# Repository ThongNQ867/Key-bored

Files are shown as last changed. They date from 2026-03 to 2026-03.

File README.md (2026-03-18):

# Key-bored
This is a split keyboard that uses XIAO nRF52840 and MX switches with hotswap, LED and 3-D printed case.

This project is a Split wireless keyboard that run on 2 Xiao nRF52840 on each side. This keyboard runs on ZMM firmware and used MX switches. I made this project because split keyboards are very expensive and I think making one will help people have the similar experience with relatively lower price. Also, the parts like Xiao are reuseable for many projects, making it really cost effective. 

How to use:
- After print the PCBA from JLC PCB or order the parts and hand soldered them, solder the hotswap sockets, Xiao, JST pins into the pcb, and finally attach the swithces into the socket.
- Wire the Xiao with your computer and flash each of them with the firmware
Basicaly we got a working keyboard now.
- For the case, put the heat inserts in, lay the pcb on top and screw it with M3 (3mm) screws.

The assembled design should look like this

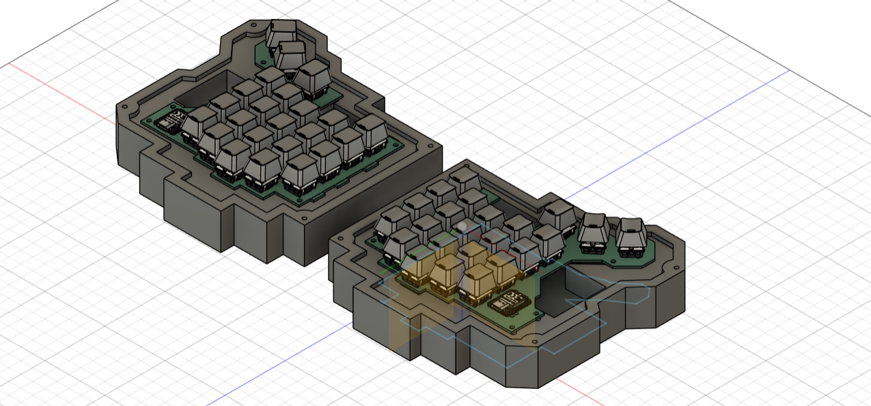
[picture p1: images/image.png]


The PCB design:

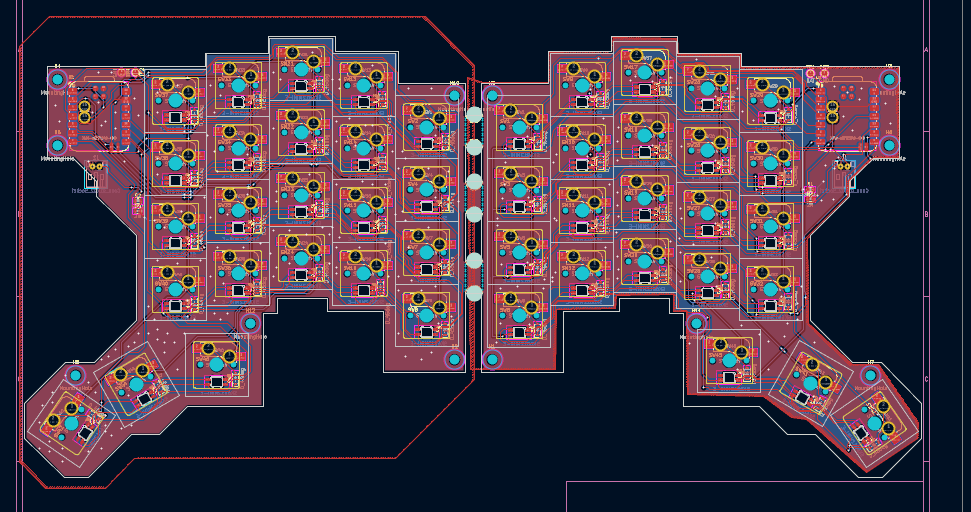
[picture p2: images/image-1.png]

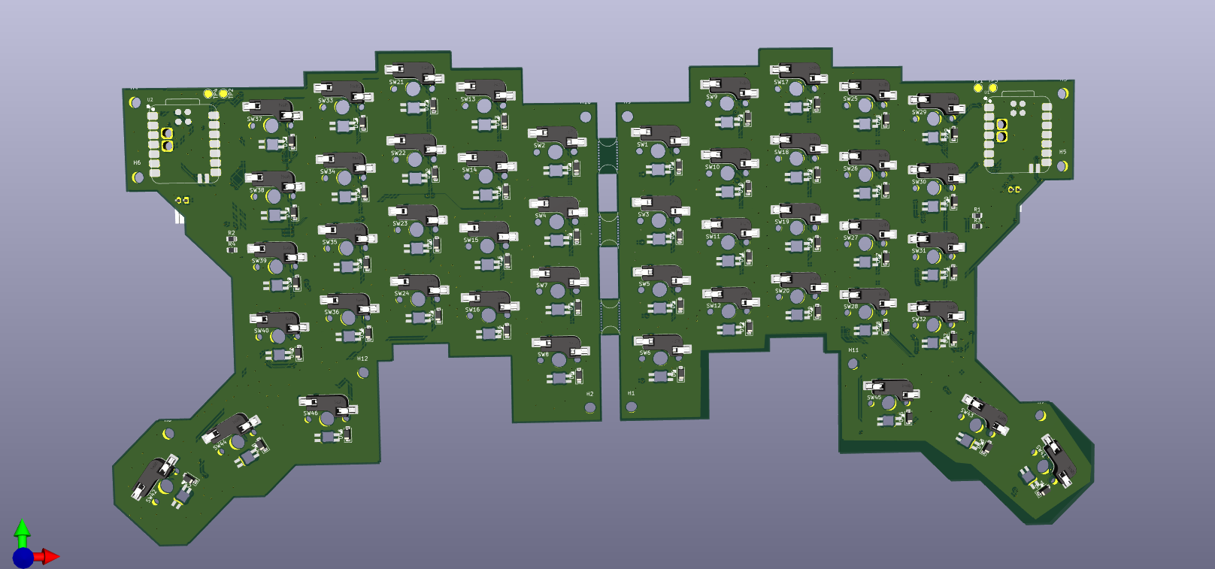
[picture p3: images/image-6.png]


Schematic (each side):

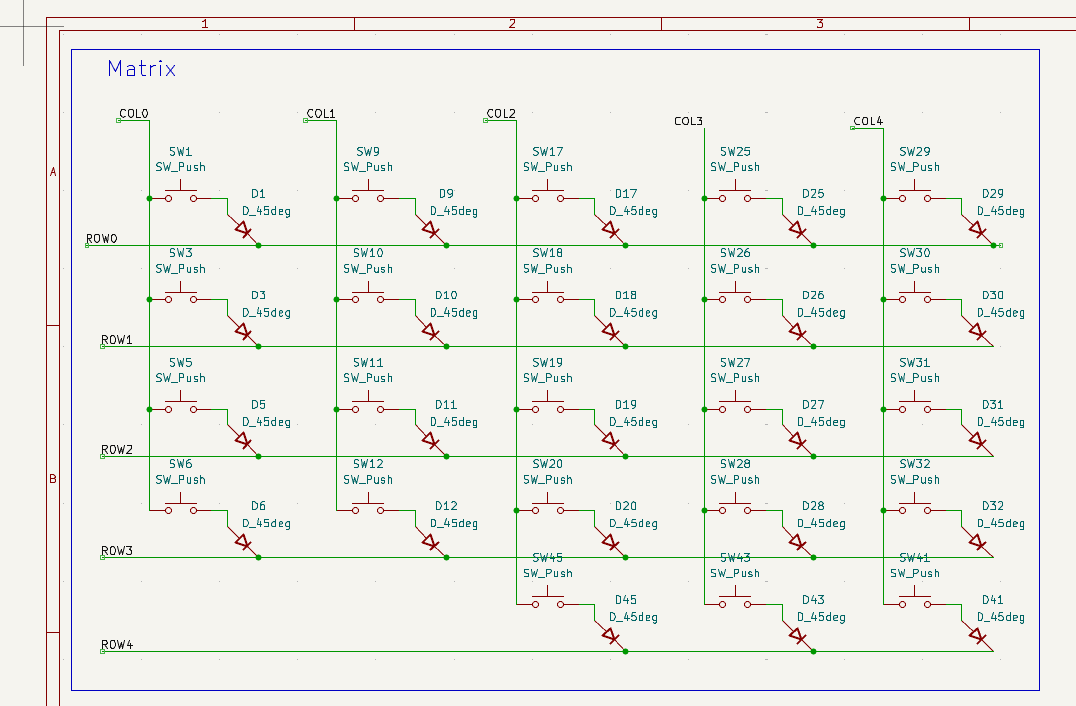
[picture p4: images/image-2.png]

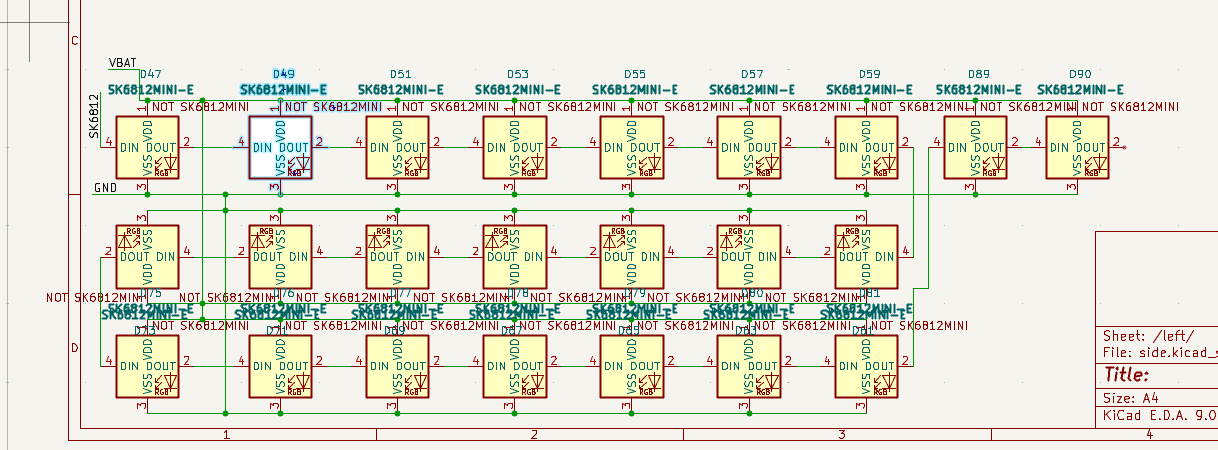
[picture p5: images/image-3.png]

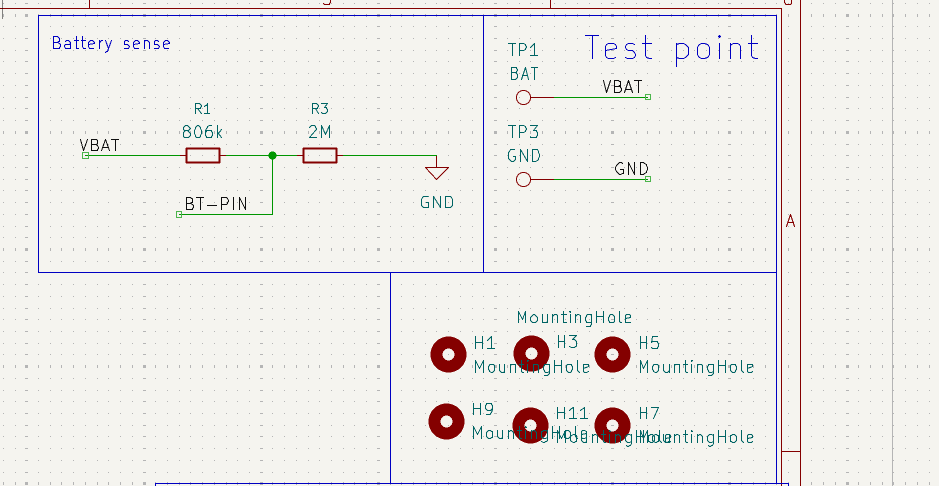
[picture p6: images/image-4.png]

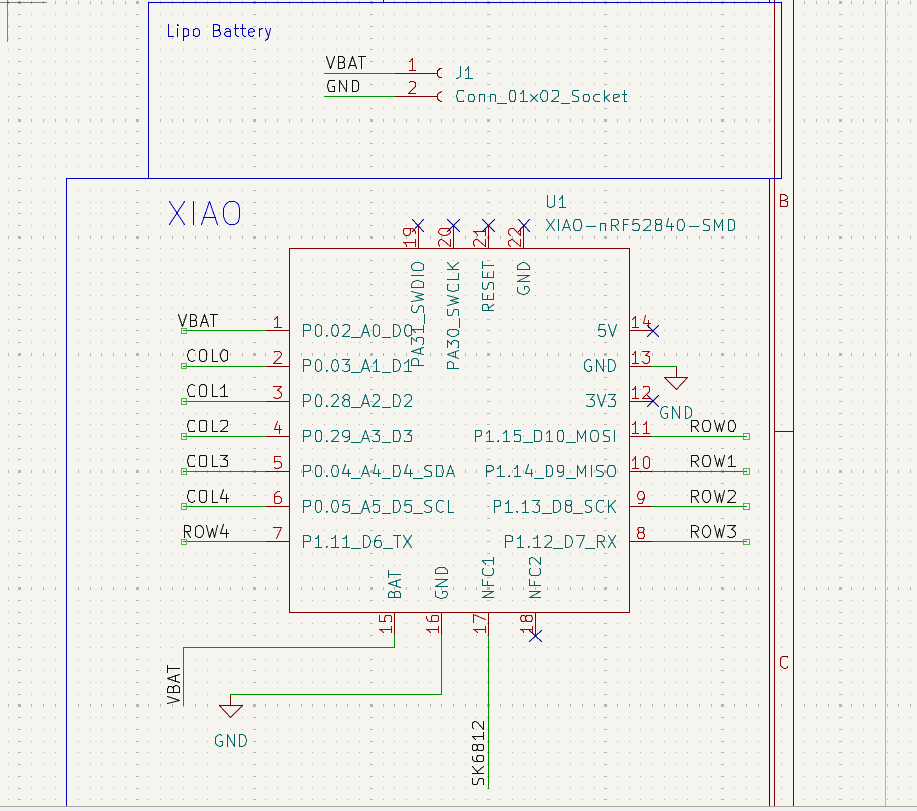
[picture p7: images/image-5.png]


BOM:

## Bill of Materials (BOM)

| Name | Comment | Footprint | JLCPCB Part # | Quantity | Links | Price (Not include shipping) |
|---|---|---|---|---|---|---|
| CR0805F88063G | 806k | R_0805_2012Metric | C101872 | 4 | https://jlcpcb.com/partdetail/LIZElec-CR0805F88063G/C101872 | Within PCB |
| 1N4148W diode | 1N4148W | D_SOD-123 | C81598 | 46 | https://jlcpcb.com/partdetail/ST_Semtech-1N4148W/C81598 | Within PCB |
| | | TestPoint_Pad_D2.0mm | | 4 | | Within PCB |
| PCB from JLCPCB | | | | 1 | | 35.71 |
| Kalih hotswap sockets | | SW_MX_HS_CPG151101S11_1u | Not from JLC PCB | 46 | https://www.aliexpress.us/item/3256809253442692.html | 12.17 |
| XIAO nRF52840 SMD | | modified-XIAO-nRF52840-SMD | Not from JLC PCB | 2 | https://www.aliexpress.us/item/3256806802639384.html | 17.96 |
| SK6812MINI - E | SK6812 | MX_SK6812MINI-E_REV | Hand solder, not from JLC PCB  | 46 | https://www.aliexpress.us/item/3256805061849599.html | 6.16 |
| JST connector | | JST_PH_S2B-PH-K_1x02_P2.00mm_Horizontal| Not from JLC PCB | 2 | https://www.aliexpress.us/item/3256804769340392.html | 1.60 |
| MX switches | | | Not from JLC PCB | 46 | https://www.aliexpress.us/item/3256805881801670.html | 8.05 |
| Rechargeable LiPo battery | 3.7V 100mAh | | Not from JLC PCB | 2 | https://www.aliexpress.us/item/3256805604531299.html | 7.01 |
| Heat inserts | M3x5x4 | | Not from JLC PCB | 10 | https://www.aliexpress.us/p/shoppingcart/index.html | 2.63 |

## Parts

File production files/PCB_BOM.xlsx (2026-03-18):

Name | Comment | Designator | Footprint | JLCPCB part # | Quantity | Links
1N4148W diode | 1N4148W | D2,D31,D33,D18,D45,D25,D17,D32,D28,D39,D43,D3,D35,D19,D42,D27,D16,D30,D23,D40,D11,D13,D4,D24,D41,D9,D10,D20,D26,D15,D34,D22,D7,D36,D38,D8,D14,D37,D12,D21,D1,D5,D29,D46,D6,D44 | D_SOD-123 | C81598 | 46 | https://jlcpcb.com/partdetail/ST_Semtech-1N4148W/C81598
SK6812MINI - E | SK6812 | D80,D65,D67,D74,D64,D49,D78,D92,D69,D53,D71,D86,D50,D81,D79,D73,D62,D83,D63,D75,D82,D56,D61,D59,D72,D70,D48,D90,D76,D58,D88,D60,D91,D85,D87,D84,D47,D66,D55,D57,D89,D77,D54,D68,D51,D52 | MX_SK6812MINI-E_REV | C5149201 | 46 | https://jlcpcb.com/partdetail/OPSCOOptoelectronics-SK6812MINIE/C5149201
CR0805F88063G | 806k | R1,R2,R3,R4 | R_0805_2012Metric | C101872 | 4 | https://jlcpcb.com/partdetail/LIZElec-CR0805F88063G/C101872

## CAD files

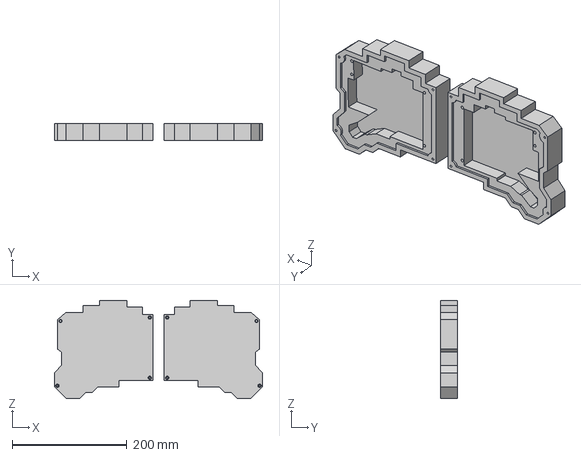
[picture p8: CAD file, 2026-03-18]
CAD/low finish.step
361.7 x 30.0 x 170.5 mm

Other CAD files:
CAD/case.f3d

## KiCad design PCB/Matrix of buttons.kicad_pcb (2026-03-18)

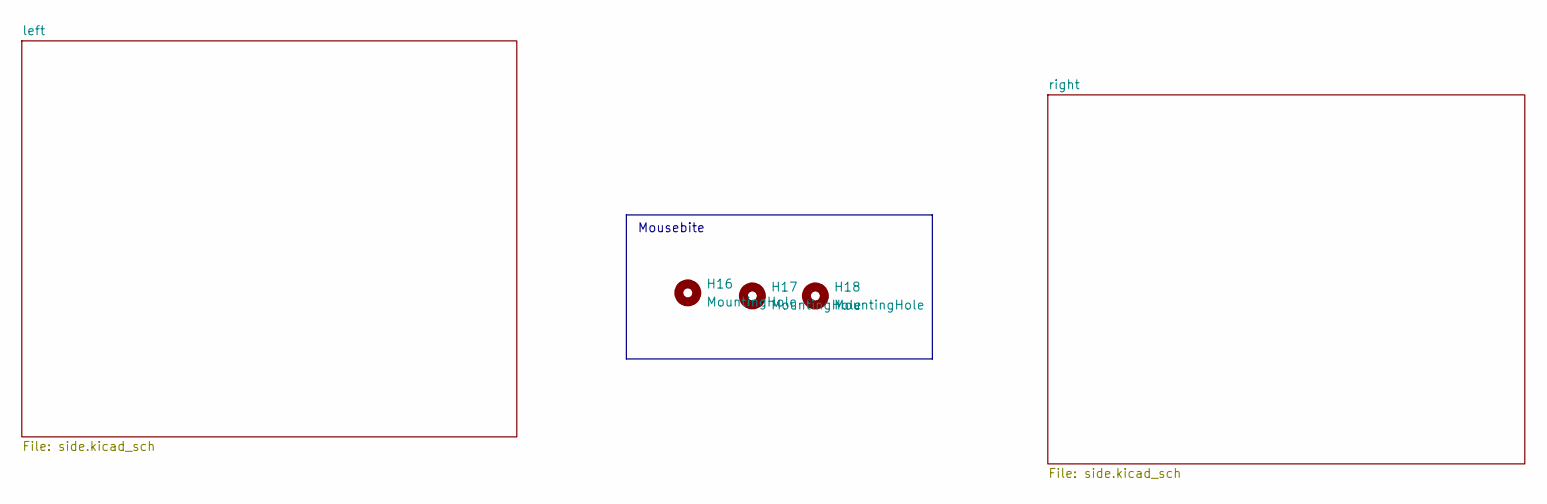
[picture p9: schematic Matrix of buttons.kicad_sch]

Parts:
H16, H17, H18: MountingHole; mouse-bite-5mm-slot

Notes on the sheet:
Mousebite

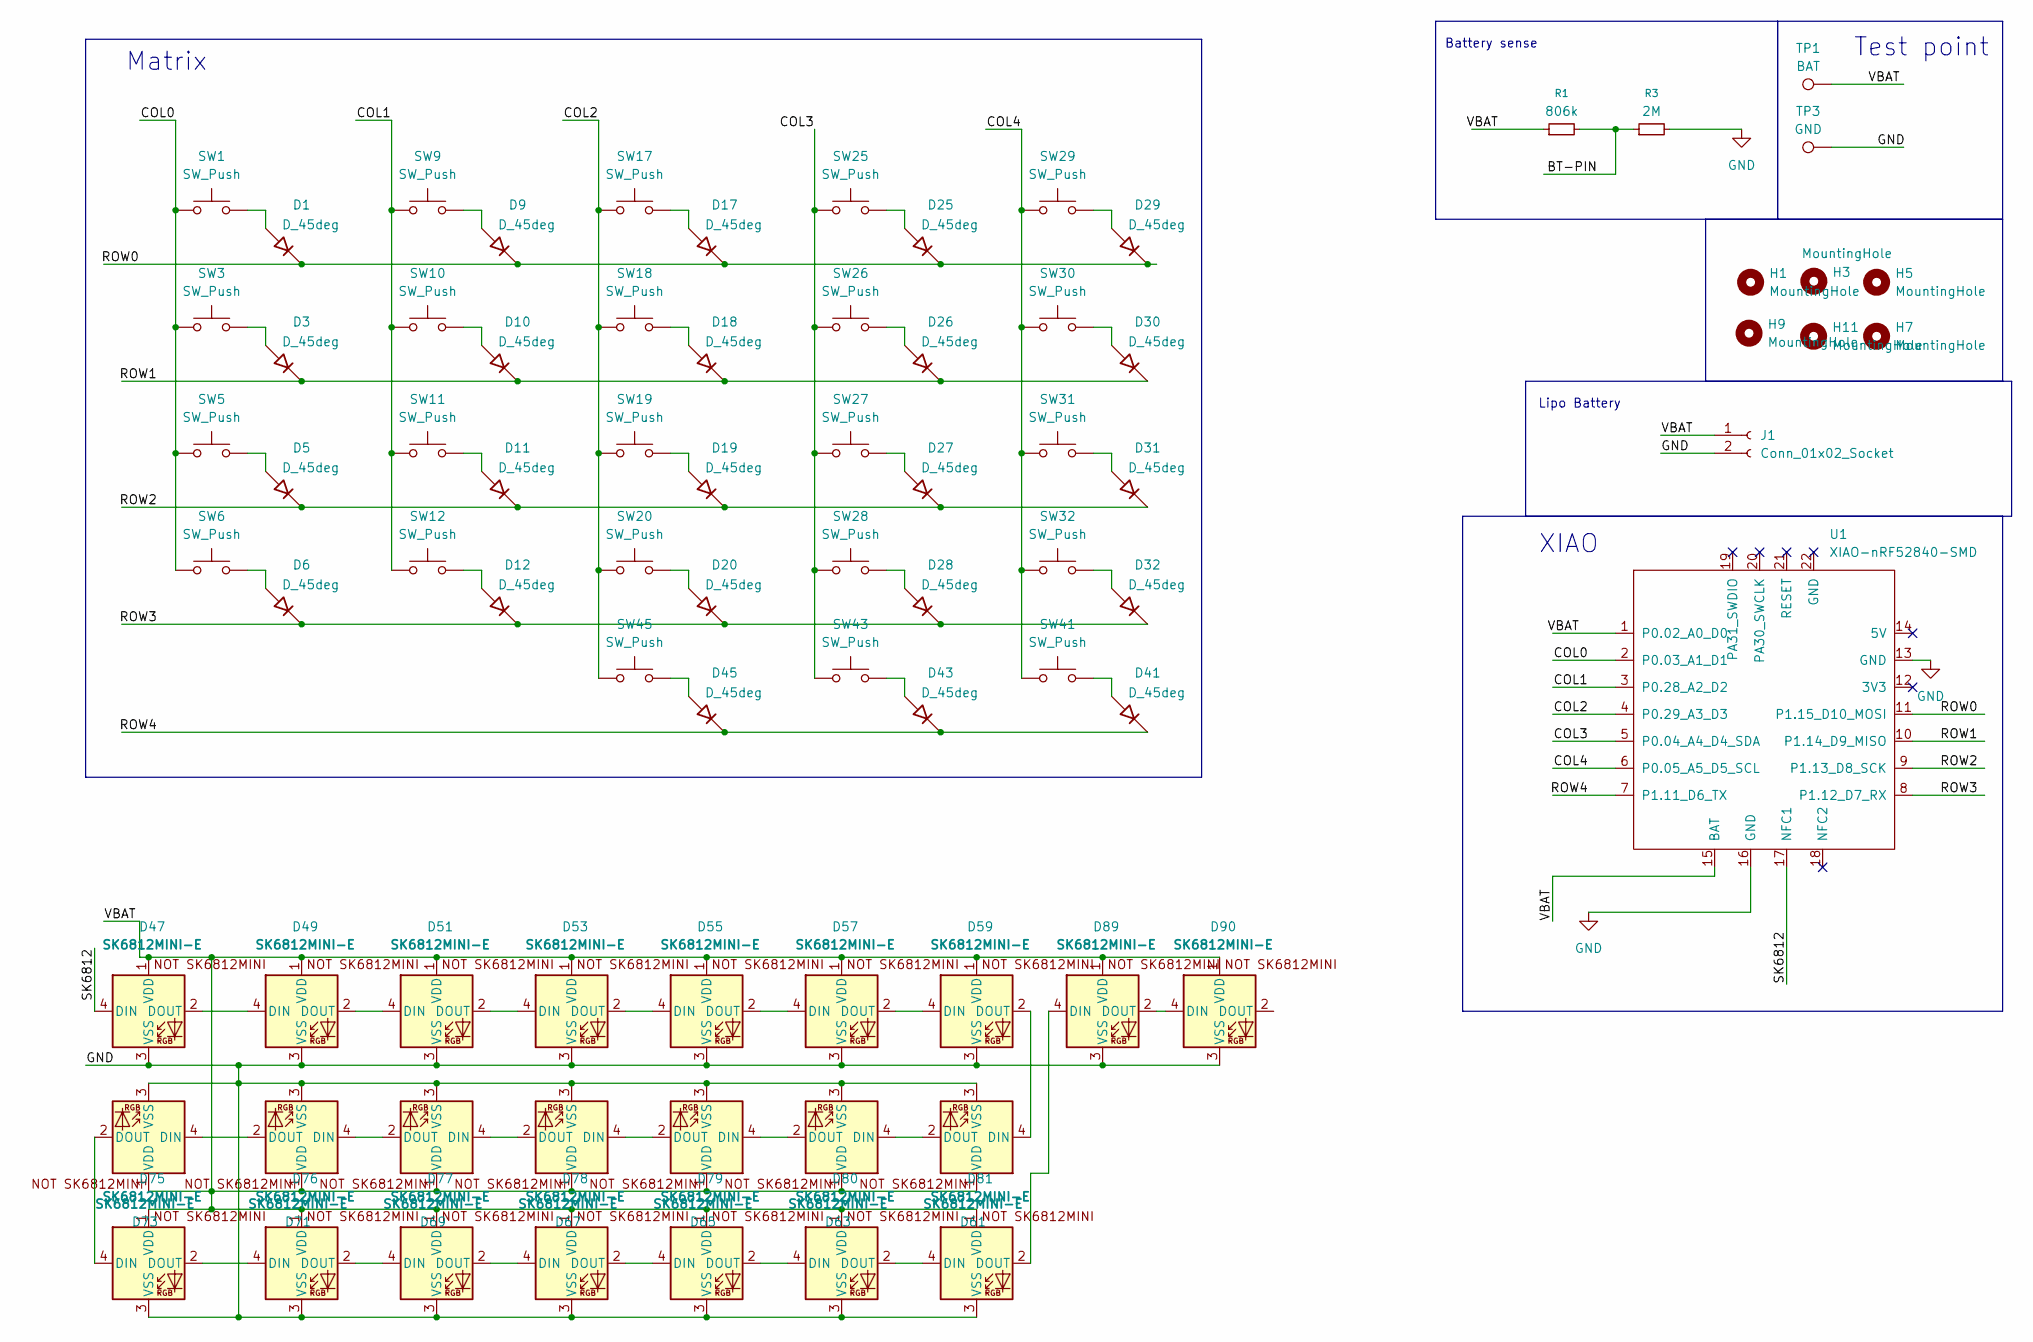
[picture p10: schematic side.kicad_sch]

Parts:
D1, D3, D5, D6, D9, D10, D11, D12, D17, D18, D19, D20, D25, D26, D27, D28, D29, D30, D31, D32, D41, D43, D45: D_45deg; D_SOD-123
D47, D49, D51, D53, D55, D57, D59, D61, D63, D65, D67, D69, D71, D73, D75, D76, D77, D78, D79, D80, D81, D89, D90: SK6812MINI-E; MX_SK6812MINI-E_REV
H1, H3, H5, H7, H9, H11: MountingHole; MountingHole_3mm
J1: Conn_01x02_Socket; JST_PH_S2B-PH-K_1x02_P2.00mm_Horizontal
R1: 806k; R_0805_2012Metric
R3: 2M; R_0805_2012Metric
SW1, SW3, SW5, SW6, SW9, SW10, SW11, SW12, SW17, SW18, SW19, SW20, SW25, SW26, SW27, SW28, SW29, SW30, SW31, SW32, SW41, SW43, SW45: SW_Push; SW_MX_HS_CPG151101S11_1u
TP1: BAT; TestPoint_Pad_D2.0mm
TP3: GND; TestPoint_Pad_D2.0mm
U1: XIAO-nRF52840-SMD; modified-XIAO-nRF52840-SMD

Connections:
/left/BT-PIN: R1.2, R3.1
/left/COL0: SW1.1, SW3.1, SW5.1, SW6.1, U1.2 (P0.03_A1_D1)
/left/COL1: SW9.1, SW10.1, SW11.1, SW12.1, U1.3 (P0.28_A2_D2)
/left/COL2: SW17.1, SW18.1, SW19.1, SW20.1, SW45.1, U1.4 (P0.29_A3_D3)
/left/COL3: SW25.1, SW26.1, SW27.1, SW28.1, SW43.1, U1.5 (P0.04_A4_D4_SDA)
/left/COL4: SW29.1, SW30.1, SW31.1, SW32.1, SW41.1, U1.6 (P0.05_A5_D5_SCL)
/left/ROW0: D1.1 (K), D9.1 (K), D17.1 (K), D25.1 (K), D29.1 (K), U1.11 (P1.15_D10_MOSI)
/left/ROW1: D3.1 (K), D10.1 (K), D18.1 (K), D26.1 (K), D30.1 (K), U1.10 (P1.14_D9_MISO)
/left/ROW2: D5.1 (K), D11.1 (K), D19.1 (K), D27.1 (K), D31.1 (K), U1.9 (P1.13_D8_SCK)
/left/ROW3: D6.1 (K), D12.1 (K), D20.1 (K), D28.1 (K), D32.1 (K), U1.8 (P1.12_D7_RX)
/left/ROW4: D41.1 (K), D43.1 (K), D45.1 (K), U1.7 (P1.11_D6_TX)
/left/SK6812: D47.4 (DIN), U1.17 (NFC1)
/left/VBAT: D47.1 (VDD), D49.1 (VDD), D51.1 (VDD), D53.1 (VDD), D55.1 (VDD), D57.1 (VDD), D59.1 (VDD), D61.1 (VDD), D63.1 (VDD), D65.1 (VDD), D67.1 (VDD), D69.1 (VDD), D71.1 (VDD), D73.1 (VDD), D75.1 (VDD), D76.1 (VDD), D77.1 (VDD), D78.1 (VDD), D79.1 (VDD), D80.1 (VDD), D81.1 (VDD), D89.1 (VDD), D90.1 (VDD), J1.1, R1.1, TP1.1, U1.1 (P0.02_A0_D0), U1.15 (BAT)
GND: D47.3 (VSS), D49.3 (VSS), D51.3 (VSS), D53.3 (VSS), D55.3 (VSS), D57.3 (VSS), D59.3 (VSS), D61.3 (VSS), D63.3 (VSS), D65.3 (VSS), D67.3 (VSS), D69.3 (VSS), D71.3 (VSS), D73.3 (VSS), D75.3 (VSS), D76.3 (VSS), D77.3 (VSS), D78.3 (VSS), D79.3 (VSS), D80.3 (VSS), D81.3 (VSS), D89.3 (VSS), D90.3 (VSS), J1.2, R3.2, TP3.1, U1.13 (GND), U1.16 (GND); also elsewhere on the board
unnamed: D1.2 (A), SW1.2
unnamed: D3.2 (A), SW3.2
unnamed: D5.2 (A), SW5.2
unnamed: D6.2 (A), SW6.2
unnamed: D9.2 (A), SW9.2
unnamed: D10.2 (A), SW10.2
unnamed: D11.2 (A), SW11.2
unnamed: D12.2 (A), SW12.2
unnamed: D17.2 (A), SW17.2
unnamed: D18.2 (A), SW18.2
unnamed: D19.2 (A), SW19.2
unnamed: D20.2 (A), SW20.2
unnamed: D25.2 (A), SW25.2
unnamed: D26.2 (A), SW26.2
unnamed: D27.2 (A), SW27.2
unnamed: D28.2 (A), SW28.2
unnamed: D29.2 (A), SW29.2
unnamed: D30.2 (A), SW30.2
unnamed: D31.2 (A), SW31.2
unnamed: D32.2 (A), SW32.2
unnamed: D41.2 (A), SW41.2
unnamed: D43.2 (A), SW43.2
unnamed: D45.2 (A), SW45.2
unnamed: D47.2 (DOUT), D49.4 (DIN)
unnamed: D49.2 (DOUT), D51.4 (DIN)
unnamed: D51.2 (DOUT), D53.4 (DIN)
unnamed: D53.2 (DOUT), D55.4 (DIN)
unnamed: D55.2 (DOUT), D57.4 (DIN)
unnamed: D57.2 (DOUT), D59.4 (DIN)
unnamed: D59.2 (DOUT), D61.4 (DIN)
unnamed: D61.2 (DOUT), D63.4 (DIN)
unnamed: D63.2 (DOUT), D65.4 (DIN)
unnamed: D65.2 (DOUT), D67.4 (DIN)
unnamed: D67.2 (DOUT), D69.4 (DIN)
unnamed: D69.2 (DOUT), D71.4 (DIN)
unnamed: D71.2 (DOUT), D73.4 (DIN)
unnamed: D73.2 (DOUT), D75.4 (DIN)
unnamed: D75.2 (DOUT), D76.4 (DIN)
unnamed: D76.2 (DOUT), D77.4 (DIN)
unnamed: D77.2 (DOUT), D78.4 (DIN)
unnamed: D78.2 (DOUT), D79.4 (DIN)
unnamed: D79.2 (DOUT), D80.4 (DIN)
unnamed: D80.2 (DOUT), D81.4 (DIN)
unnamed: D81.2 (DOUT), D89.4 (DIN)
unnamed: D89.2 (DOUT), D90.4 (DIN)

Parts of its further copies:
D2, D4, D7, D8, D13, D14, D15, D16, D21, D22, D23, D24, D33, D34, D35, D36, D37, D38, D39, D40, D42, D44, D46: D_45deg; D_SOD-123
D48, D50, D52, D54, D56, D58, D60, D62, D64, D66, D68, D70, D72, D74, D82, D83, D84, D85, D86, D87, D88, D91, D92: SK6812MINI-E; MX_SK6812MINI-E_REV
H2, H4, H6, H8, H10, H12: MountingHole; MountingHole_3mm
J2: Conn_01x02_Socket; JST_PH_S2B-PH-K_1x02_P2.00mm_Horizontal
R2: 806k; R_0805_2012Metric
R4: 2M; R_0805_2012Metric
SW2, SW4, SW7, SW8, SW13, SW14, SW15, SW16, SW21, SW22, SW23, SW24, SW33, SW34, SW35, SW36, SW37, SW38, SW39, SW40, SW42, SW44, SW46: SW_Push; SW_MX_HS_CPG151101S11_1u
TP2: BAT; TestPoint_Pad_D2.0mm
TP4: GND; TestPoint_Pad_D2.0mm
U2: XIAO-nRF52840-SMD; modified-XIAO-nRF52840-SMD

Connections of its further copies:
/right/BT-PIN: R2.2, R4.1
/right/COL0: SW2.1, SW4.1, SW7.1, SW8.1, U2.2 (P0.03_A1_D1)
/right/COL1: SW13.1, SW14.1, SW15.1, SW16.1, U2.3 (P0.28_A2_D2)
/right/COL2: SW21.1, SW22.1, SW23.1, SW24.1, SW46.1, U2.4 (P0.29_A3_D3)
/right/COL3: SW33.1, SW34.1, SW35.1, SW36.1, SW44.1, U2.5 (P0.04_A4_D4_SDA)
/right/COL4: SW37.1, SW38.1, SW39.1, SW40.1, SW42.1, U2.6 (P0.05_A5_D5_SCL)
/right/ROW0: D2.1 (K), D13.1 (K), D21.1 (K), D33.1 (K), D37.1 (K), U2.11 (P1.15_D10_MOSI)
/right/ROW1: D4.1 (K), D14.1 (K), D22.1 (K), D34.1 (K), D38.1 (K), U2.10 (P1.14_D9_MISO)
/right/ROW2: D7.1 (K), D15.1 (K), D23.1 (K), D35.1 (K), D39.1 (K), U2.9 (P1.13_D8_SCK)
/right/ROW3: D8.1 (K), D16.1 (K), D24.1 (K), D36.1 (K), D40.1 (K), U2.8 (P1.12_D7_RX)
/right/ROW4: D42.1 (K), D44.1 (K), D46.1 (K), U2.7 (P1.11_D6_TX)
/right/SK6812: D48.4 (DIN), U2.17 (NFC1)
/right/VBAT: D48.1 (VDD), D50.1 (VDD), D52.1 (VDD), D54.1 (VDD), D56.1 (VDD), D58.1 (VDD), D60.1 (VDD), D62.1 (VDD), D64.1 (VDD), D66.1 (VDD), D68.1 (VDD), D70.1 (VDD), D72.1 (VDD), D74.1 (VDD), D82.1 (VDD), D83.1 (VDD), D84.1 (VDD), D85.1 (VDD), D86.1 (VDD), D87.1 (VDD), D88.1 (VDD), D91.1 (VDD), D92.1 (VDD), J2.1, R2.1, TP2.1, U2.1 (P0.02_A0_D0), U2.15 (BAT)
GND: D48.3 (VSS), D50.3 (VSS), D52.3 (VSS), D54.3 (VSS), D56.3 (VSS), D58.3 (VSS), D60.3 (VSS), D62.3 (VSS), D64.3 (VSS), D66.3 (VSS), D68.3 (VSS), D70.3 (VSS), D72.3 (VSS), D74.3 (VSS), D82.3 (VSS), D83.3 (VSS), D84.3 (VSS), D85.3 (VSS), D86.3 (VSS), D87.3 (VSS), D88.3 (VSS), D91.3 (VSS), D92.3 (VSS), J2.2, R4.2, TP4.1, U2.13 (GND), U2.16 (GND); also elsewhere on the board
unnamed: D2.2 (A), SW2.2
unnamed: D4.2 (A), SW4.2
unnamed: D7.2 (A), SW7.2
unnamed: D8.2 (A), SW8.2
unnamed: D13.2 (A), SW13.2
unnamed: D14.2 (A), SW14.2
unnamed: D15.2 (A), SW15.2
unnamed: D16.2 (A), SW16.2
unnamed: D21.2 (A), SW21.2
unnamed: D22.2 (A), SW22.2
unnamed: D23.2 (A), SW23.2
unnamed: D24.2 (A), SW24.2
unnamed: D33.2 (A), SW33.2
unnamed: D34.2 (A), SW34.2
unnamed: D35.2 (A), SW35.2
unnamed: D36.2 (A), SW36.2
unnamed: D37.2 (A), SW37.2
unnamed: D38.2 (A), SW38.2
unnamed: D39.2 (A), SW39.2
unnamed: D40.2 (A), SW40.2
unnamed: D42.2 (A), SW42.2
unnamed: D44.2 (A), SW44.2
unnamed: D46.2 (A), SW46.2
unnamed: D48.2 (DOUT), D50.4 (DIN)
unnamed: D50.2 (DOUT), D52.4 (DIN)
unnamed: D52.2 (DOUT), D54.4 (DIN)
unnamed: D54.2 (DOUT), D56.4 (DIN)
unnamed: D56.2 (DOUT), D58.4 (DIN)
unnamed: D58.2 (DOUT), D60.4 (DIN)
unnamed: D60.2 (DOUT), D62.4 (DIN)
unnamed: D62.2 (DOUT), D64.4 (DIN)
unnamed: D64.2 (DOUT), D66.4 (DIN)
unnamed: D66.2 (DOUT), D68.4 (DIN)
unnamed: D68.2 (DOUT), D70.4 (DIN)
unnamed: D70.2 (DOUT), D72.4 (DIN)
unnamed: D72.2 (DOUT), D74.4 (DIN)
unnamed: D74.2 (DOUT), D82.4 (DIN)
unnamed: D82.2 (DOUT), D83.4 (DIN)
unnamed: D83.2 (DOUT), D84.4 (DIN)
unnamed: D84.2 (DOUT), D85.4 (DIN)
unnamed: D85.2 (DOUT), D86.4 (DIN)
unnamed: D86.2 (DOUT), D87.4 (DIN)
unnamed: D87.2 (DOUT), D88.4 (DIN)
unnamed: D88.2 (DOUT), D91.4 (DIN)
unnamed: D91.2 (DOUT), D92.4 (DIN)

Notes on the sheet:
Battery sense
XIAO
Matrix
Lipo Battery
Test point

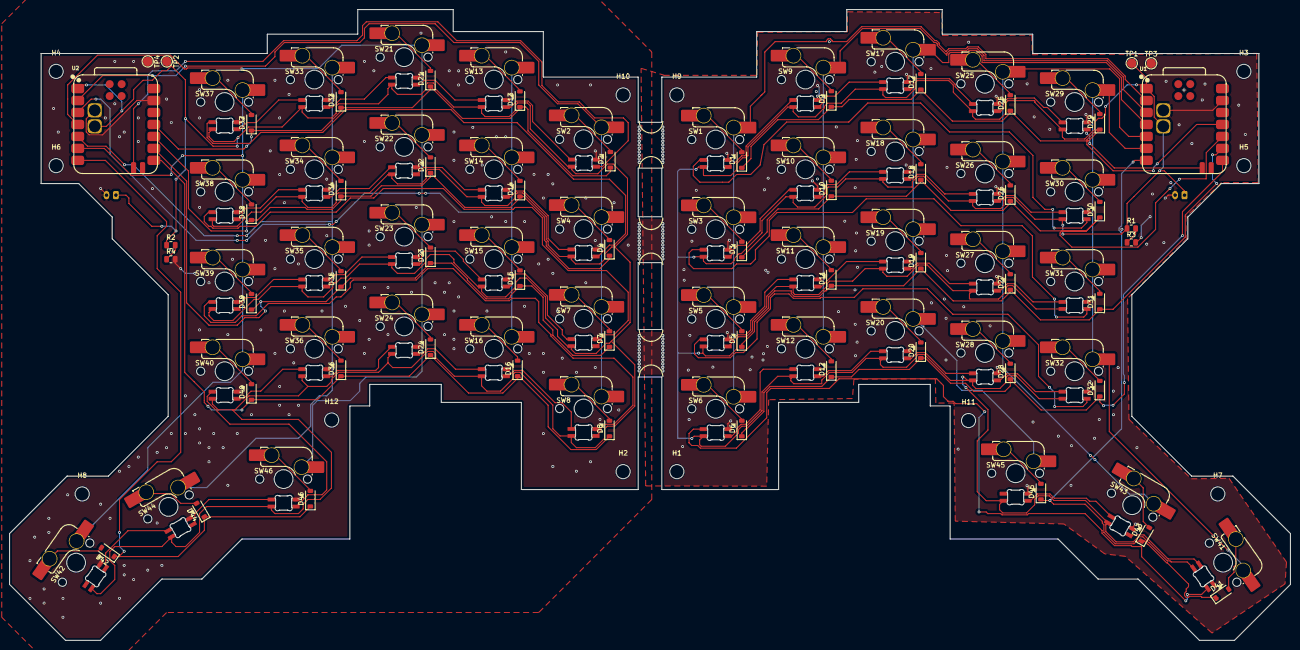
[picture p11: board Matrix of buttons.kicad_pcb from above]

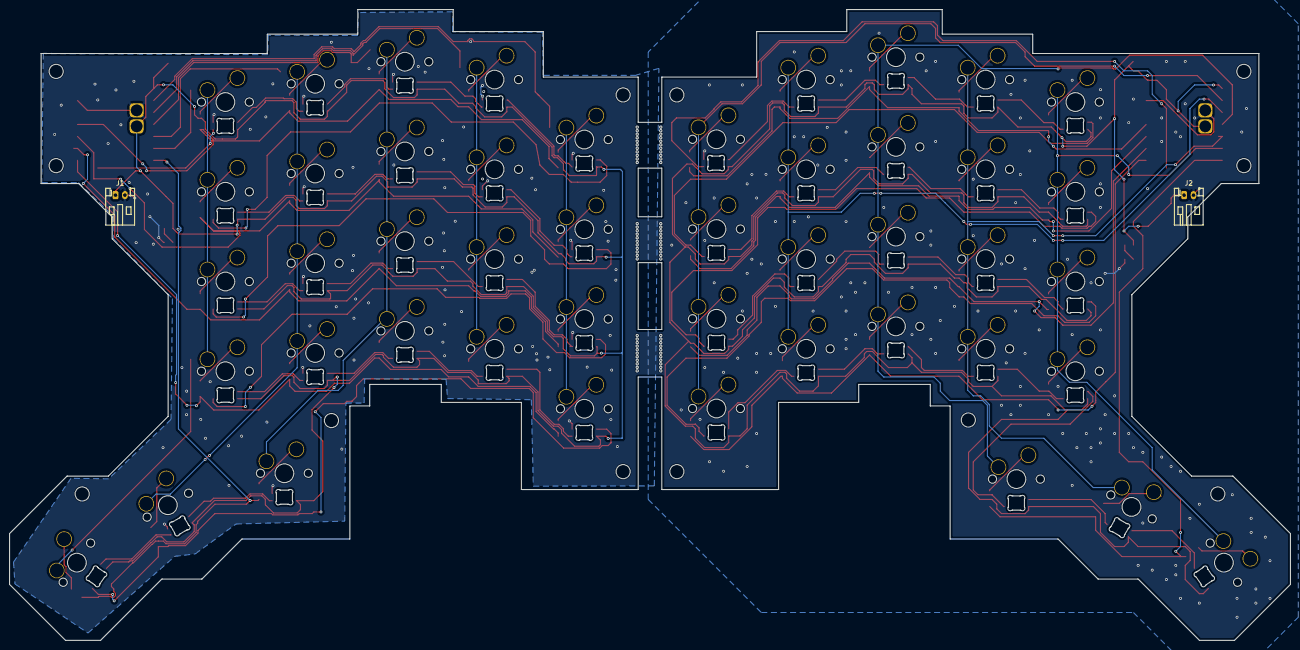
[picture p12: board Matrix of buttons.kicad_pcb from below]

Board: 2 copper layers, 271.9 x 133.9 mm, 165 parts (48 on the bottom side), 117 nets.

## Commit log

2026-03-18 bom to csv
    [BOM.csv]
2026-03-18 add CAD files and PCB files
    [BOM.csv, BOM.xlsx, Matrix of buttons.kicad_pcb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]
2026-03-18 organize image
    [BOM.csv, BOM.xlsx]
